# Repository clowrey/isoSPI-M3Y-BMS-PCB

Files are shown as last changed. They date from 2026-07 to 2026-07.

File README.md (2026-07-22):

# CellKeeper BMS — Rev1

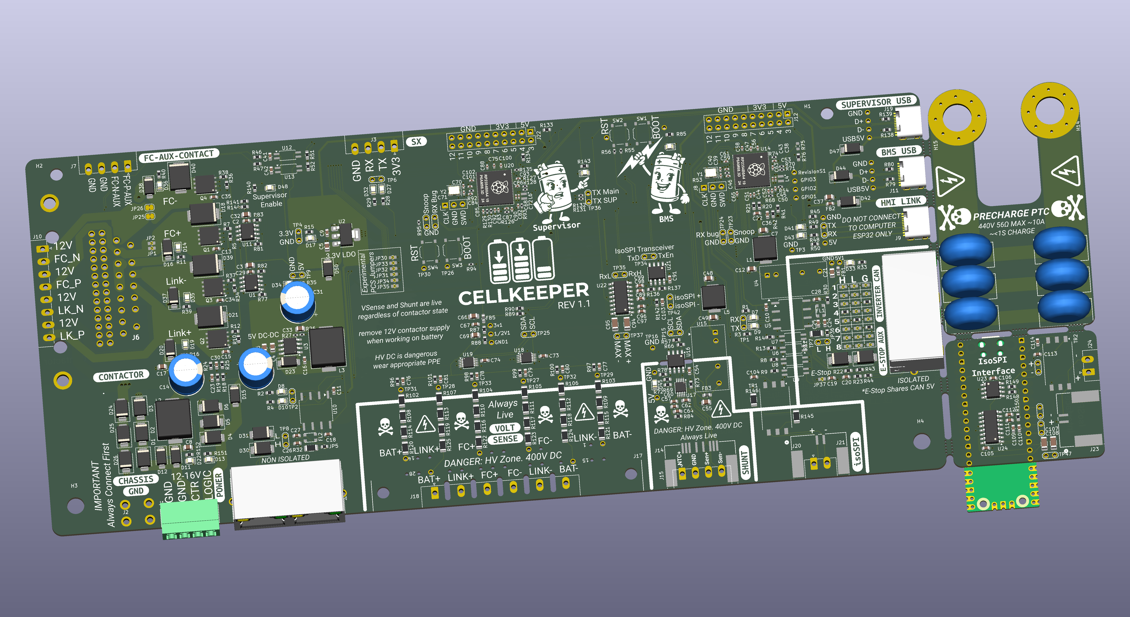
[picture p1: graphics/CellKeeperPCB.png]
CellKeeper PCB


KiCad PCB design for the **CellKeeper Battery Management System**, a replacement BMS controller for battery packs using the isoSPI protocol.

## Overview

- **MCU:** Raspberry Pi RP2354B (dual Cortex-M33 @ 150 MHz)
- **Current sensing:** TI INA228 (20-bit ADC, shunt-based)
- **Pack voltage:** 6-channel monitoring via precision dividers
- **BMB communication:** isoSPI master with galvanic isolation (Manchester encoding via PIO)
- **CAN bus:** 500 kbps, hardware transceiver
- **Contactor control:** 4-channel PWM outputs with inrush limiting
- **Input:** 12 V nominal; rated for up to 400 V DC pack voltage

## Repository Contents

| Path | Description |
|---|---|
| `CellKeeper.kicad_pro` | KiCad project file |
| `CellKeeper.kicad_sch` | Schematic |
| `CellKeeper.kicad_pcb` | PCB layout |
| `CellKeeper_Local.kicad_sym` / `CellKeeper_Local.pretty/` | Local symbol and footprint libraries |
| `CellKeeper.3dshapes/` | 3D models |
| `graphics/` | Silkscreen artwork and images |
| `production/` | Manufacturing outputs |
| `python_scripts/` | Utility scripts |

## Getting Started

1. Install [KiCad 10.0+](https://www.kicad.org/download/)
2. Clone this repository
3. Open `CellKeeper.kicad_pro` — project libraries load from the local `sym-lib-table` and `fp-lib-table`

## Safety

⚠️ This board interfaces with 400 V battery packs that can deliver **lethal** current. Only qualified personnel should work on high-voltage systems. This is a Rev1 development design — untested, no warranty, use at your own risk.

## Acknowledgments

- **Damien Maguire & Tom de Bree** — Original BATMan BMS software

## License

GPL-3.0 — see [LICENSE](LICENSE).

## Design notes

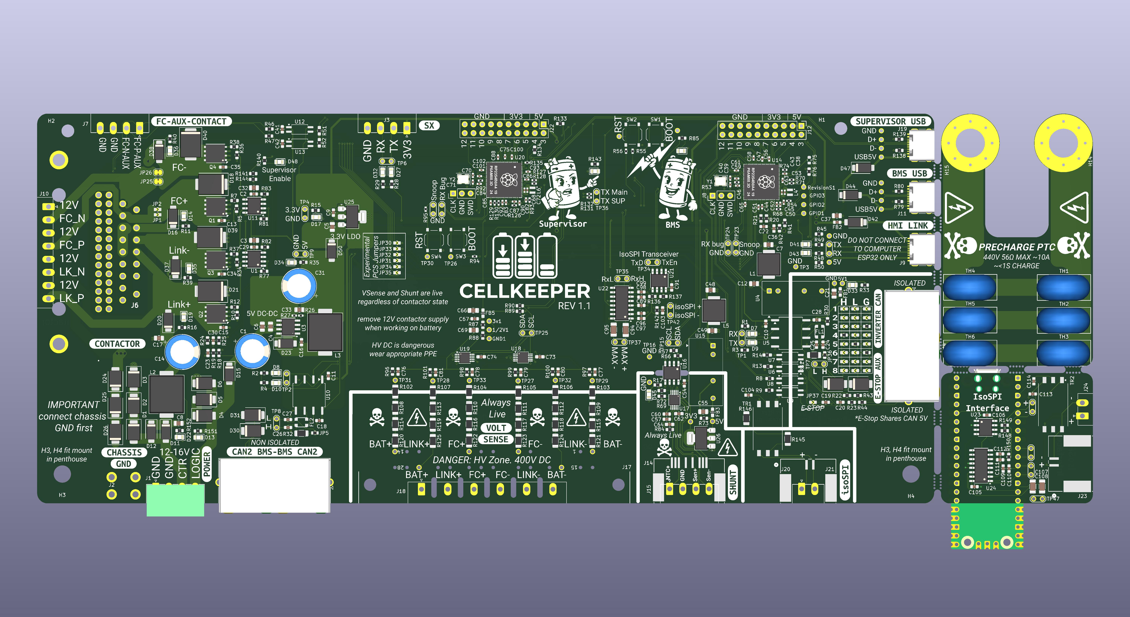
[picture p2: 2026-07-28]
CellKeeper_1v1.jpg

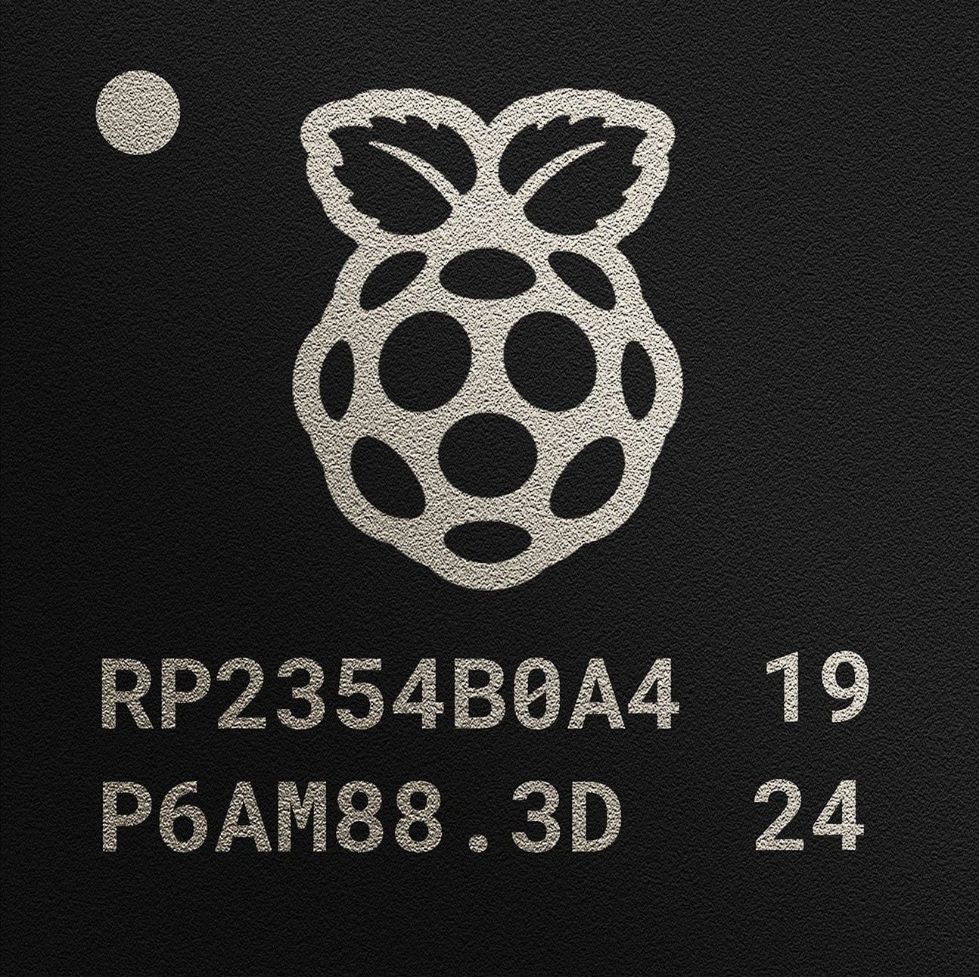
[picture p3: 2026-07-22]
graphics/raspberry-pi-rp2354b.jpg

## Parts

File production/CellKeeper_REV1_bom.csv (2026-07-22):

Designator | Footprint | Quantity | Value | LCSC Part #
1/2V1, 3V1, 5V1, GND1, GPIO1, GPIO2, GPIO3 | BMS_Library__TestPoint_THTPad_D1.5mm_Drill1.0mm | 7 | TP
A1 | Module__RaspberryPi_Pico_Common_Unspecified | 1 | RaspberryPi_Pico
C1, C14, C31 | Capacitor_THT__CP_Radial_D10.0mm_P5.00mm | 3 | 680uF | C46550429
C10, C104, C105, C106, C11, C114, C13, C15, C16, C18, C2, C22, C23, C28, C29, C30, C34, C35, C36, C54, C60, C76, C77, C78, C79, C80, C81, C89, C91 | Capacitor_SMD__C_0603_1608Metric | 29 | 100nF | C14663
C100, C101, C102, C44, C46, C47, C50, C51, C53, C56, C58, C59, C61, C63, C65, C75, C83, C84, C85, C86, C88, C90, C92, C93 | Capacitor_SMD__C_0402_1005Metric | 24 | 100n | C1525
C103, C113, C24, C25, C26, C27 | Capacitor_SMD__C_0603_1608Metric | 6 | 100pF | C14858
C107, C108, C94, C95 | Capacitor_SMD__C_1206_3216Metric | 4 | 1nF | C9196
C109, C110, C111, C112, C19, C20, C41, C42, C57, C67, C96, C97, C98, C99 | Capacitor_SMD__C_0603_1608Metric | 14 | 1uF | C15849
C12, C33, C37, C48, C49, C5, C69, C7 | Capacitor_SMD__C_0805_2012Metric | 8 | 22uF | C45783
C17, C21, C3, C32, C4, C55, C6, C8 | Capacitor_SMD__C_0805_2012Metric | 8 | 10uF | C440198
C38, C43, C68, C72 | RP2350_80QFN_minimal__C_0402_1005Metric_small_pads | 4 | 4.7u | C23733
C39, C40, C70, C71 | Capacitor_SMD__C_0402_1005Metric | 4 | 15pF | C1548
C45, C52, C82, C87 | Capacitor_SMD__C_0402_1005Metric | 4 | 4.7u | C23733
C62, C64, C73, C74 | Capacitor_SMD__C_0603_1608Metric_Pad1.08x0.95mm_HandSolder | 4 | 100nf | C14663
C66 | Capacitor_SMD__C_0805_2012Metric_Pad1.18x1.45mm_HandSolder | 1 | 10uF | C440198
C9 | Capacitor_SMD__C_0603_1608Metric | 1 | 4.7uF | C19666
D1, D2, D24, D25, D26, D28, D29, D3, D30, D31, D4, D5, D6 | Diode_SMD__D_SMB | 13 | SMB6.8CA | C78395
D10, D27, D41, D46, D49, D9 | LED_SMD__LED_0805_2012Metric | 6 | Red | C84256
D11, D12, D15, D16, D20, D23, D37, D38, D42, D44, D47, D50 | Diode_SMD__D_SMA | 12 | SS54 | C22452
D13, D17, D22, D33, D34, D45 | LED_SMD__LED_0805_2012Metric | 6 | White | C34499
D14, D19, D32, D35, D36, D43, D48, D7, D8 | LED_SMD__LED_0805_2012Metric | 9 | Green | C2297
D18, D21, D39, D40 | Diode_SMD__D_SMC | 4 | SMCJ33CA | C224050
FB1, FB3, FB5 | Inductor_SMD__L_0603_1608Metric_Pad1.05x0.95mm_HandSolder | 3 | 600R@100MHz | C1002
FB2 | Capacitor_SMD__C_0603_1608Metric | 1 | 120Ω@100MHz | C14709
FL1, FL2 | BMS_Library__FILTER-SMD_4P-L3.2-W2.5-BL | 2 | SDCW3225S-2-102TF | C192586
J1 | BMS_Library__PhoenixContact_MC_1_5_4-G-3.81_1x04_P3.81mm_Horizontal_1.4mmPin | 1 | Screw_Terminal_01x04
J11, J19, J9 | BMS_Library__USB_C_Receptacle_HRO_TYPE-C-31-M-12 | 3 | USB_C_Receptacle_USB2.0_16P | C2765186
J14 | BMS_Library__CONN_ZE05H-8DP-2H_HIR | 1 | OEM Shunt Connector | C17284895
J17 | BMS_Library__CONN_173864-1_TYC_Empty_Pins | 1 | OEM HV Sense Connector | C573648
J2 | BMS_Library__XFCN_T34008_M3_Terminal_Frame_PCB | 1 | Screw_Terminal_01x01 | C481446
J20, J23 | BMS_Library__CONN_SD-34912-001_02_MOL | 2 | OEM Connector | C587318
J4, J5 | Connector_RJ__RJ45_HCTL_HC-RJ45-5JA-2-2-Y | 2 | 8P8C_LED_Shielded_x2 | C3010546
J6 | BMS_Library__S44BRAD1AK | 1 | OEM Connector
JP10, JP11, JP15, JP36, JP5, JP6 | BMS_Library__J_0603_jumper | 6 | 0r | C21189
L1, L5 | Inductor_SMD__L_Changjiang_FXL0630 | 2 | 6.8uh | C167221
L2, L3 | Inductor_SMD__L_Changjiang_FXL1040 | 2 | 22uh 5.5A | C475917
L4, L6 | RP2350_80QFN_minimal__L_pol_2016 | 2 | 3.3uh | C42411119
Q1, Q2, Q3, Q4 | BMS_Library__TDSON-8_5x6_ | 4 | BSC0805LS | C534374
R1, R100, R101, R11, R140, R16, R17, R2, R29, R33, R35, R39, R40, R41, R6, R78, R96, R97, R98, R99 | Resistor_SMD__R_0603_1608Metric | 20 | 24k | C23352
R10, R18, R24, R34, R36, R5 | Resistor_SMD__R_0603_1608Metric | 6 | 100k | C25803
R102, R103, R104, R105, R106, R107, R108, R109, R110, R111, R112, R113, R114, R115, R116, R117, R118, R119, R120, R121, R122, R123, R124, R125 | Resistor_SMD__R_1206_3216Metric | 24 | 3M | C488822
R12, R37, R38, R7 | Resistor_SMD__R_0603_1608Metric | 4 | 33R | C23140
R126, R54, R68, R93 | Resistor_SMD__R_0402_1005Metric | 4 | 33r | C25105
R127, R128, R70, R71 | Resistor_SMD__R_0402_1005Metric | 4 | 22R | C25092
R129, R130, R131, R132, R135, R27, R53, R55, R56, R74, R92, R94, R95 | Resistor_SMD__R_0402_1005Metric | 13 | 1k | C11702
R13, R14, R51, R52 | Resistor_SMD__R_0603_1608Metric_Pad0.98x0.95mm_HandSolder | 4 | 10k | C25804
R133, R134, R141, R22, R23, R46, R47, R48, R49, R8, R9 | Resistor_SMD__R_0603_1608Metric | 11 | 1k | C21190
R136, R137, R148, R149 | Resistor_SMD__R_0603_1608Metric | 4 | 47r | C23182
R138, R139, R143, R144, R45, R57, R66, R69, R72, R77, R79, R80, R81, R82, R83, R85, R89, R90 | Resistor_SMD__R_0603_1608Metric | 18 | 5.1k | C23186
R142, R150 | Resistor_SMD__R_0603_1608Metric | 2 | 100R | C22775
R145, R146 | Resistor_SMD__R_1206_3216Metric | 2 | 1M | C17927
R15, R19, R20, R21, R25, R28, R3, R4, R42, R50, R84 | Resistor_SMD__R_0603_1608Metric | 11 | 10k | C25804
R26 | Resistor_SMD__R_0402_1005Metric | 1 | 3.3k | C25890
R30, R73 | Resistor_SMD__R_0603_1608Metric | 2 | 510r | C23193
R31, R32 | Resistor_SMD__R_1206_3216Metric | 2 | 120r | C17909
R43, R44 | Resistor_SMD__R_0603_1608Metric | 2 | 2.2k | C4190
R76 | Resistor_SMD__R_0603_1608Metric | 1 | 0r | C21189
R87, R88 | Resistor_SMD__R_0603_1608Metric | 2 | 220r | C22962
SW1, SW2, SW3, SW4 | Button_Switch_SMD__SW_Push_1P1T_XKB_TS-1187A | 4 | TS-1187A-B-A-B | C318884
TH1, TH2, TH3, TH4, TH5, TH6 | BMS_Library__RV_Disc_D15.5mm_W7.5mm_P5.0mm | 6 | B59451C1130B070 | C2762811
TR1, TR2 | BMS_Library__HM2113ZNLT | 2 | HM2113ZNLT | C5730533
U1, U11 | Package_SO__SOIC-8_3.9x4.9mm_P1.27mm | 2 | UCC27524DR | C465729
U10, U5 | Package_SO__SOP-8_6.62x9.15mm_P2.54mm | 2 | ISO1050DUB | C16428
U12, U13, U6, U7, U8, U9 | Package_SO__SSOP-4_4.4x2.6mm_P1.27mm | 6 | LTV-217-B-G | C115450
U14, U20 | RP2350_80QFN_minimal__RP2350-QFN-80-1EP_10x10_P0.4mm_EP3.4x3.4mm_ThermalVias | 2 | RP2354B | C39843328
U15, U4 | BMS_Library__H0505S-1WR2 | 2 | F0505S-1WR3 | C7465182
U16 | Package_SO__SOIC-8_3.9x4.9mm_P1.27mm | 1 | ISO1540 | C179739
U17 | Package_SO__TSSOP-10_3x3mm_P0.5mm | 1 | INA228 | C5214669
U18, U19 | Package_SO__TSSOP-10_3x3mm_P0.5mm | 2 | ADS1115 | C37593
U2 | Package_TO_SOT_SMD__SOT-223-3_TabPin2 | 1 | AMS1117-3.3 | C6186
U21, U23 | Package_SO__SOIC-8_3.9x4.9mm_P1.27mm | 2 | SP3485EN-L/TR | C8963
U22, U24 | Package_SO__SOIC-16_3.9x9.9mm_P1.27mm | 2 | AM26LV32EIDR | C527448
U3 | Package_SO__TI_SO-PowerPAD-8_ThermalVias | 1 | TPS5430DDAR | C9864
Y1, Y2 | Crystal__Crystal_SMD_3225-4Pin_3.2x2.5mm | 2 | ABM8-272-T3 | C20625731

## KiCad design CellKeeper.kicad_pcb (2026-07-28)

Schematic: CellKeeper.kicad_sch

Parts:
1/2V1, 3v1, 5V1: TP; BMS_Library__TestPoint_THTPad_D1.5mm_Drill1.0mm
A1: RaspberryPi_Pico; Module__RaspberryPi_Pico_Common_Unspecified
BT1, BT2, BT3, BT4, BT5, BT6, BT7, BT8: ~100V Brick
C1, C14, C31: 680uF; Capacitor_THT__CP_Radial_D10.0mm_P5.00mm; Voltage 35V Polymer; JLCPCB Part # C46550429
C2, C10, C11, C13, C15, C16, C18, C22, C23, C28, C29, C30, C34, C35, C36, C54, C60, C89, C91, C104, C105, C106, C114: 100nF; Capacitor_SMD__C_0603_1608Metric; JLCPCB Part # C14663
C3, C4, C6, C8, C17, C32: 10uF; Capacitor_SMD__C_0805_2012Metric; Voltage 50V; JLCPCB Part # C440198
C5, C7, C12, C33, C37, C48, C49, C69: 22uF; Capacitor_SMD__C_0805_2012Metric; Voltage 25V X5R; JLCPCB Part # C45783
C9: 4.7uF; Capacitor_SMD__C_0603_1608Metric; JLCPCB Part # C19666
C19, C20, C41, C42, C67, C96, C97, C98, C99, C109, C110, C111, C112: 1uF; Capacitor_SMD__C_0603_1608Metric; JLCPCB Part # C15849
C21, C55, C116: 10uF; Capacitor_SMD__C_0805_2012Metric; Voltage 50V X5R; JLCPCB Part # C440198
C24, C25, C26, C27, C103, C113: 100pF; Capacitor_SMD__C_0603_1608Metric; JLCPCB Part # C14858
C38, C43, C68, C72: 4.7u; RP2350_80QFN_minimal__C_0402_1005Metric_small_pads; JLCPCB Part # C23733
C39, C40, C70, C71: 15pF; Capacitor_SMD__C_0402_1005Metric; JLCPCB Part # C1548
C44, C46, C47, C50, C51, C53, C56, C58, C59, C61, C63, C65, C75, C83, C84, C85, C86, C88, C90, C92, C93, C100, C101, C102: 100n; Capacitor_SMD__C_0402_1005Metric; JLCPCB Part # C1525
C45, C52, C82, C87: 4.7u; Capacitor_SMD__C_0402_1005Metric; JLCPCB Part # C23733
C62, C64: 100nf; Capacitor_SMD__C_0603_1608Metric_Pad1.08x0.95mm_HandSolder; JLCPCB Part # C14663
C66: 10uF; Capacitor_SMD__C_0805_2012Metric_Pad1.18x1.45mm_HandSolder; Voltage 50V; JLCPCB Part # C440198
C73, C74: 100nF; Capacitor_SMD__C_0603_1608Metric_Pad1.08x0.95mm_HandSolder; JLCPCB Part # C14663
C76, C77, C78, C79, C80, C81: 100nf; Capacitor_SMD__C_0603_1608Metric; JLCPCB Part # C14663
C94, C95, C107, C108: 1nF; Capacitor_SMD__C_1206_3216Metric; JLCPCB Part # C9196
Cell1, Cell2, Cell3: Battery_Cell
D1, D2, D3, D4, D5, D6, D24, D25, D26, D28, D29, D30, D31: SMB6.8CA; Diode_SMD__D_SMB; JLCPCB Part # C78395
D7, D8, D14, D19, D32, D35, D36, D43, D48: Green; LED_SMD__LED_0805_2012Metric; JLCPCB Part # C2297
D9, D10, D27, D41, D46, D49: Red; LED_SMD__LED_0805_2012Metric; JLCPCB Part # C84256
D11, D12, D15, D16, D20, D23, D37, D38, D42, D44, D47, D50: SS54; Diode_SMD__D_SMA; JLCPCB Part # C22452
D13, D17, D22, D33, D34, D45: White; LED_SMD__LED_0805_2012Metric; JLCPCB Part # C34499
D18, D21, D39, D40: SMCJ33CA; Diode_SMD__D_SMC; JLCPCB Part # C224050
F1, F3: Pyro Fuse
F2, F4: 63A HV DC
FB1, FB3, FB5: 600R@100MHz; Inductor_SMD__L_0603_1608Metric_Pad1.05x0.95mm_HandSolder; JLCPCB Part # C1002
FB2: 120Ω@100MHz; Capacitor_SMD__C_0603_1608Metric; JLCPCB Part # C14709
FL1, FL2: SDCW3225S-2-102TF; BMS_Library__FILTER-SMD_4P-L3.2-W2.5-BL; JLCPCB Part # C192586
GND1: TP; BMS_Library__TestPoint_THTPad_D1.5mm_Drill1.0mm
GPIO1, GPIO2, GPIO3: TP; BMS_Library__TestPoint_THTPad_D1.5mm_Drill1.0mm
H1, H2: MountingHole_Pad; MountingHole__MountingHole_3.7mm; not fitted
H3, H4: MountingHole_Pad; MountingHole__MountingHole_5mm; not fitted
H5, H6, H7, H8, H9, H10, H11, H12, H13: Mouse Bites 2mm; BMS_Library__mouse-bite-2mm-slot-min
H14, H15: MountingHole_Pad; MountingHole__MountingHole_8.4mm_M8_Pad_Via
J1: Screw_Terminal_01x04; BMS_Library__PhoenixContact_MC_1_5_4-G-3.81_1x04_P3.81mm_Ho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
J2: Screw_Terminal_01x01; BMS_Library__XFCN_T34008_M3_Terminal_Frame_PCB; JLCPCB Part # C481446
J3, J7, J15: Screw_Terminal_01x04; BMS_Library__PhoenixContact_MC_1_5_4-G-3.81_1x04_P3.81mm_Ho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; not fitted
J4, J5: 8P8C_LED_Shielded_x2; Connector_RJ__RJ45_HCTL_HC-RJ45-5JA-2-2-Y; JLCPCB Part # C3010546
J6: OEM Connector; BMS_Library__S44BRAD1AK; Mfr. # S44B-RAD1AK
J8, J16: Conn_01x03; Connector_PinHeader_2.54mm__PinHeader_1x03_P2.54mm_Vertical; not fitted
J9, J11, J19: USB_C_Receptacle_USB2.0_16P; BMS_Library__USB_C_Receptacle_HRO_TYPE-C-31-M-12; JLCPCB Part # C2765186
J10: 3.81P Screw Terminal; BMS_Library__PhoenixContact_MC_1_5_8-G-3.81_1x08_P3.81mm_Ho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; not fitted
J12, J22: Conn_02x10_Odd_Even; Connector_PinHeader_2.54mm__PinHeader_2x10_P2.54mm_Vertical; not fitted
J13: USB_C_Receptacle_USB2.0_16P
J14: OEM Shunt Connector; BMS_Library__CONN_ZE05H-8DP-2H_HIR; MFR.Part # ZE05H-8DP-2H; JLCPCB Part # C17284895
J17: OEM HV Sense Connector; BMS_Library__CONN_173864-1_TYC_Empty_Pins; MFR Part # 173864-1; JLCPCB Part # C573648
J18: 7.62mm Pitch Screw Terminal; Connector_Phoenix_GMSTB__PhoenixContact_GMSTBA_2_5_6-G-7_62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; not fitted
J20, J23: OEM Connector; BMS_Library__CONN_SD-34912-001_02_MOL; MFR.Part # 349128020; JLCPCB Part # C587318
J21, J24: 3.81P Screw Terminal; BMS_Library__PhoenixContact_MC_1_5_2-G-3.81_1x02_P3.81mm_Ho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; not fitted
JP1, JP2, JP3, JP4, JP7, JP8, JP9, JP12, JP13, JP14, JP16, JP17, JP18, JP19, JP20, JP21, JP22, JP23, JP24, JP27, JP28, JP29, JP30, JP31, JP32, JP33, JP34, JP35, JP37: 0r; BMS_Library__J_0603_jumper; JLCPCB Part # C21189; not fitted
JP5, JP6, JP10, JP11, JP15, JP36: 0r; BMS_Library__J_0603_jumper; JLCPCB Part # C21189
JP25, JP26: jumper-bridged; Jumper__SolderJumper-2_P1.3mm_Bridged_RoundedPad1.0x1.5mm
K1, K6: Link Positive
K2, K7: Link Negative
K3, K9: FC Positive
K4, K8: FC Negative
K5, K10: Inverter
L1, L5: 6.8uh; Inductor_SMD__L_Changjiang_FXL0630; JLCPCB Part # C167221
L2, L3: 22uh 5.5A; Inductor_SMD__L_Changjiang_FXL1040; JLCPCB Part # C475917
L4, L6: 3.3uh; RP2350_80QFN_minimal__L_pol_2016; JLCPCB Part # C42411119
Q1, Q2, Q3, Q4: BSC0805LS; BMS_Library__TDSON-8_5x6_; JLCPCB Part # C534374
R1, R2, R11, R16, R29, R33, R35, R39, R40, R41, R96, R97, R98, R99, R100, R101, R140: 24k; Resistor_SMD__R_0603_1608Metric; JLCPCB Part # C23352
R3, R4, R15, R17, R19, R20, R21, R25, R28, R42, R50, R84: 10k; Resistor_SMD__R_0603_1608Metric; JLCPCB Part # C25804
R5, R10, R18, R24, R34, R36, R151, R152: 100k; Resistor_SMD__R_0603_1608Metric; JLCPCB Part # C25803
R7, R12, R37, R38: 33R; Resistor_SMD__R_0603_1608Metric; JLCPCB Part # C23140
R8, R9, R22, R23, R46, R47, R48, R49, R133, R134, R141: 1k; Resistor_SMD__R_0603_1608Metric; JLCPCB Part # C21190
R13, R14, R51, R52: 10k; Resistor_SMD__R_0603_1608Metric_Pad0.98x0.95mm_HandSolder; JLCPCB Part # C25804
R26: 3.3k; Resistor_SMD__R_0402_1005Metric; JLCPCB Part # C25890
R27, R53, R55, R56, R74, R92, R94, R95, R129, R130, R131, R132, R135: 1k; Resistor_SMD__R_0402_1005Metric; JLCPCB Part # C11702
R30, R73: 510r; Resistor_SMD__R_0603_1608Metric; JLCPCB Part # C23193
R31, R32: 120r; Resistor_SMD__R_1206_3216Metric; JLCPCB Part # C17909
R43, R44: 2.2k; Resistor_SMD__R_0603_1608Metric; JLCPCB Part # C4190
R45, R57, R66, R69, R72, R77, R79, R80, R81, R82, R83, R85, R89, R90, R138, R139, R143, R144: 5.1k; Resistor_SMD__R_0603_1608Metric; JLCPCB Part # C23186
R54, R68, R93, R126: 33r; Resistor_SMD__R_0402_1005Metric; JLCPCB Part # C25105
R58, R59, R60, R61, R62, R63, R64, R65: 18r
R67: 12.24R
R70, R71, R127, R128: 22R; Resistor_SMD__R_0402_1005Metric; JLCPCB Part # C25092
R75: 47k; Resistor_SMD__R_0603_1608Metric; JLCPCB Part # C25819; not fitted
R76: 0r; Resistor_SMD__R_0603_1608Metric; JLCPCB Part # C21189
R86, R147: 25296nΩ
R87, R88: 220r; Resistor_SMD__R_0603_1608Metric; JLCPCB Part # C22962
R91: 27R 50W
R102, R103, R104, R105, R106, R107, R108, R109, R110, R111, R112, R113, R114, R115, R116, R117, R118, R119, R120, R121, R122, R123, R124, R125: 3M; Resistor_SMD__R_1206_3216Metric; JLCPCB Part # C488822
R136, R137, R148, R149: 47r; Resistor_SMD__R_0603_1608Metric; JLCPCB Part # C23182
R142, R150: 100R; Resistor_SMD__R_0603_1608Metric; JLCPCB Part # C22775
R145, R146: 1M; Resistor_SMD__R_1206_3216Metric; JLCPCB Part # C17927
RevisionS1: TP; BMS_Library__TestPoint_THTPad_D1.5mm_Drill1.0mm
SW1, SW2, SW3, SW4: TS-1187A-B-A-B; Button_Switch_SMD__SW_Push_1P1T_XKB_TS-1187A; JLCPCB Part # C318884
TH1, TH2, TH3, TH4, TH5, TH6: B59451C1130B070; BMS_Library__RV_Disc_D15.5mm_W7.5mm_P5.0mm; JLCPCB Part # C2762811
TP1, TP2, TP4, TP6, TP7, TP8, TP9, TP10, TP15, TP23, TP24, TP25, TP34, TP35, TP36, TP37, TP43, TP44, TP45, TP46, TP47, TP48: TestPoint_2Pole; BMS_Library__TestPoint_2Pads_Pitch2.54mm_Pad1.5_Drill1.0mm
TP3, TP5, TP11, TP12, TP13, TP14, TP16, TP17, TP18, TP19, TP20, TP21, TP22, TP26, TP27, TP28, TP29, TP30, TP31, TP32, TP33, TP38, TP39, TP40, TP41, TP49: TP; BMS_Library__TestPoint_THTPad_D1.5mm_Drill1.0mm
TP42: TestPoint_2Pole; BMS_Library__TestPoint_2Pads_Pitch2.54mm_Pad1.5_Drill1.0mm; not fitted
TR1, TR2: HM2113ZNLT; BMS_Library__HM2113ZNLT; JLCPCB Part # C5730533
U1, U11: UCC27524DR; Package_SO__SOIC-8_3.9x4.9mm_P1.27mm; JLCPCB Part # C465729
U3: TPS5430DDAR; Package_SO__TI_SO-PowerPAD-8_ThermalVias; LCSC Part C9864
U4, U15: F0505S-1WR3; BMS_Library__H0505S-1WR2; JLCPCB Part # C7465182
U5, U10: ISO1050DUB; Package_SO__SOP-8_6.62x9.15mm_P2.54mm; LCSC Part # C16428
U6, U7, U8, U9, U12, U13: LTV-217-B-G; Package_SO__SSOP-4_4.4x2.6mm_P1.27mm; JLCPCB Part # C115450
U14, U20: RP2354B; RP2350_80QFN_minimal__RP2350-QFN-80-1EP_10x10_P0.4mm_EP3.4x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; JLCPCB Part # C39843328
U16: ISO1540; Package_SO__SOIC-8_3.9x4.9mm_P1.27mm; JLCPCB Part # C179739
U17: INA228; Package_SO__TSSOP-10_3x3mm_P0.5mm; JLCPCB Part # C5214669
U18, U19: ADS1115; Package_SO__TSSOP-10_3x3mm_P0.5mm; LCSC Part # C37593
U21, U23: SP3485EN-L/TR; Package_SO__SOIC-8_3.9x4.9mm_P1.27mm; JLCPCB Part # C8963
U22, U24: AM26LV32EIDR; Package_SO__SOIC-16_3.9x9.9mm_P1.27mm; JLCPCB Part # C527448
U25, U26: TLV1117LV33DCYR; Package_TO_SOT_SMD__SOT-223-3_TabPin2; JLCPCB Part # C15578
Y1, Y2: ABM8-272-T3; Crystal__Crystal_SMD_3225-4Pin_3.2x2.5mm; JLCPCB Part # C20625731

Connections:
3.3V Sense: C22.2, R20.2, R21.1, U14.49 (GPIO40_ADC0)
5V Sense: C36.2, R41.2, R42.1, U14.52 (GPIO41_ADC1)
+1V1: C43.1, C44.1, C46.1, C47.1, L4.1, U14.10 (DVDD), U14.32 (DVDD), U14.51 (DVDD), U14.65 (VREG_FB)
+1V1_2: C72.1, C75.1, C83.1, C84.1, L6.1, U20.10 (DVDD), U20.32 (DVDD), U20.51 (DVDD), U20.65 (VREG_FB)
+3.3V: C9.2, C10.1, C11.1, C38.1, C50.1, C51.1, C53.1, C56.1, C58.1, C59.1, C61.1, C63.1, C65.1, C66.2, C68.1, C85.1, C86.1, C88.1, C89.1, C90.1, C91.2, C92.1, C93.1, C100.1, C101.1, C102.1, D7.2 (A), D9.2 (A), D41.2 (A), D43.2 (A), FB5.1, J3.1, J12.5, J12.7, J12.9, J22.5, J22.7, J22.9, JP35.2, R2.1, R4.1, R15.1, R20.1, R28.1, R29.1, R54.2, R57.1, R66.1, R68.2, R75.1, R89.1, R90.1, R93.2, R126.2, R135.1, TP4.2, U5.1 (VCC1), U6.4, U7.4, U10.1 (VCC1), U12.4, U13.4, U14.5 (IOVDD), U14.15 (IOVDD), U14.24 (IOVDD), U14.29 (IOVDD), U14.41 (IOVDD), U14.50 (IOVDD), U14.60 (IOVDD), U14.64 (VREG_VIN), U14.68 (USB_OTP_VDD), U14.69 (QSPI_IOVDD), U14.76 (IOVDD), U16.1 (VCC1), U20.5 (IOVDD), U20.15 (IOVDD), U20.24 (IOVDD), U20.29 (IOVDD), U20.41 (IOVDD), U20.50 (IOVDD), U20.60 (IOVDD), U20.64 (VREG_VIN), U20.68 (USB_OTP_VDD), U20.69 (QSPI_IOVDD), U20.76 (IOVDD), U21.8 (VCC), U22.4 (G), U22.16 (VDD), U25.2 (VO)
+3.3V2: A1.36 (3V3), C105.1, C106.2, U23.8 (VCC), U24.4 (G), U24.16 (VDD)
+3.3VSen: 3v1.1 (1_1), C67.2, C73.2, C74.2, FB5.2, R87.1, U18.8 (VDD), U19.1 (ADDR), U19.8 (VDD)
+5V: C2.2, C3.2, C7.2, C18.2, C29.2, C31.1, C32.2, C33.2, C37.2, C41.2, C42.2, C48.2, D50.2 (A), FB2.2, J12.1, J12.3, J22.1, J22.3, L1.2, L3.1, L5.2, R26.1, R35.1, R41.1, TP9.2, U1.6 (V_{DD}), U10.8 (VCC2), U11.6 (V_{DD}), U12.1, U13.1
+LDO_IN: C5.2, D44.1 (K), D47.1 (K), D50.1 (K), U25.3 (VI)
/Blue: J4.4, JP15.2, JP16.1, JP18.1
/Brown: J4.8, JP19.2, JP20.1, JP23.1
/CAN2 H: C26.2, D30.2 (A2), FL2.2, J5.4, J5.16, R32.2, TP8.2
/CAN2 L: C27.1, D31.1 (A1), FL2.3, J5.5, J5.17, JP5.1, TP8.1
/CAN 5V: 5V1.1 (1_1), C28.2, FB1.2, R22.2, R30.1, R33.1, R43.2, U5.8 (VCC2)
/CAN H: C24.2, D28.2 (A2), FL1.2, JP3.1, JP7.1, JP9.1, JP13.1, JP15.1, JP19.1, JP21.1, JP27.1, JP36.1, TP7.2
/CAN L: C25.1, D29.1 (A1), FL1.3, JP4.2, JP8.2, JP10.2, JP14.2, JP16.2, JP20.2, JP22.2, JP28.2, R31.1, TP7.1
/Contactor_Input: D1.2 (A2), D11.2 (A), D12.2 (A), J1.3
/FC Neg: H15.1 (1_1), K4.13, K8.13, K10.2, TH4.2, TH5.2, TH6.2
/FC-CTR-NEG-AUX-D: J6.17, J7.2, R47.1
/FC-CTR-POS-AUX-D: J6.18, J7.1, R46.1
/FC-Neg-Jumper: C35.2, D36.1 (K), D38.2 (A), D40.2 (A2), JP25.1 (A), JP26.1 (A), Q4.5 (D)
/FC-Pos-Jumper: C13.2, D14.1 (K), D16.2 (A), D18.2 (A2), JP1.1, JP2.1, Q1.5 (D)
/GPIO0: R74.2, U14.77 (GPIO0)
/GPIO3: J12.2, U14.80 (GPIO3)
/GPIO25: R85.1, U14.26 (GPIO25)
/GPIO44_ADC4: GPIO1.1 (1_1), U14.55 (GPIO44_ADC4)
/GPIO45_ADC5: GPIO2.1 (1_1), U14.56 (GPIO45_ADC5)
/GPIO46_ADC6: GPIO3.1 (1_1), U14.57 (GPIO46_ADC6)
/GPIO47_ADC7: R75.2, R76.1, RevisionS1.1 (1_1), U14.58 (GPIO47_ADC7)
/Grn: J4.6, JP7.2, JP8.1, JP11.1
/Logic_Input: D4.2 (A2), D15.2 (A), J1.4, R151.2
/MCU2_GPIO0: R135.2, U20.77 (GPIO0)
/MCU2_GPIO1: R131.2, U20.78 (GPIO1)
/MCU2_GPIO2: R132.2, U20.79 (GPIO2)
/MCU2_GPIO3: J22.2, U20.80 (GPIO3)
/MCU2_GPIO4: J22.4, U20.1 (GPIO4)
/MCU2_GPIO5: J22.6, U20.2 (GPIO5)
/MCU2_GPIO6: J22.8, R133.1, U20.3 (GPIO6)
/MCU2_GPIO7: J22.10, U20.4 (GPIO7)
/MCU2_GPIO8: J22.12, R134.1, U20.6 (GPIO8)
/MCU2_GPIO9: J22.14, U20.7 (GPIO9)
/MCU2_GPIO10: J22.16, U20.8 (GPIO10)
/MCU2_GPIO12: J22.20, U20.11 (GPIO12)
/MCU2_GPIO13: U20.12 (GPIO13)
/MCU2_GPIO14: R140.1, R141.1, U20.13 (GPIO14)
/MCU2_GPIO15: U20.14 (GPIO15)
/MCU2_GPIO16: U20.16 (GPIO16)
/MCU2_GPIO17: U20.17 (GPIO17)
/MCU2_GPIO18: U20.18 (GPIO18)
/MCU2_GPIO19: U20.19 (GPIO19)
/MCU2_GPIO20: U20.20 (GPIO20)
/MCU2_GPIO21: U20.21 (GPIO21)
/MCU2_GPIO22: U20.22 (GPIO22)
/MCU2_GPIO23: U20.23 (GPIO23)
/MCU2_GPIO24: U20.25 (GPIO24)
/MCU2_GPIO25: R143.1, U20.26 (GPIO25)
/MCU2_GPIO26: U20.27 (GPIO26)
/MCU2_GPIO27: U20.28 (GPIO27)
/MCU2_GPIO33: U20.42 (GPIO33)
/MCU2_GPIO34: U20.43 (GPIO34)
/MCU2_GPIO35: U20.44 (GPIO35)
/MCU2_GPIO36: U20.45 (GPIO36)
/MCU2_GPIO37: U20.46 (GPIO37)
/MCU2_GPIO38: R129.2, U20.47 (GPIO38)
/MCU2_GPIO39: R130.2, U20.48 (GPIO39)
/Orange: J4.2, JP21.2, JP22.1, JP24.1
/PH: C16.1, D23.1 (K), L3.2, U3.8 (PH)
/QSPI2_SCLK: U20.71 (QSPI_SCLK)
/QSPI2_SD0: U20.72 (QSPI_SD0)
/QSPI2_SD1: U20.74 (QSPI_SD1)
/QSPI2_SD2: U20.73 (QSPI_SD2)
/QSPI2_SD3: U20.70 (QSPI_SD3)
/QSPI2_SS: R94.1, U20.75 (QSPI_SS)
/QSPI_SCLK: U14.71 (QSPI_SCLK)
/QSPI_SD0: U14.72 (QSPI_SD0)
/QSPI_SD1: U14.74 (QSPI_SD1)
/QSPI_SD2: U14.73 (QSPI_SD2)
/QSPI_SD3: U14.70 (QSPI_SD3)
/QSPI_SS: R55.1, U14.75 (QSPI_SS)
/RUN: R56.2, SW2.2, TP14.1 (1_1)
/RUN_2: R95.1, U20.35 (RUN)
/SWCLK: J8.1, U14.33 (SWCLK)
/SWCLK_2: J16.1, U20.33 (SWCLK)
/SWD: J8.3, U14.34 (SWD)
/SWD_2: J16.3, U20.34 (SWD)
/Serial API 5V Diode: D42.1 (K), J9.A4 (VBUS), J9.A9 (VBUS), J9.B4 (VBUS), J9.B9 (VBUS), TP13.1 (1_1)
/Serial API RX: J9.A7 (D-), J9.B7 (D-), R48.1, R50.2, TP10.1
/Serial API TX: J9.A6 (D+), J9.B6 (D+), R49.1, TP10.2
/USB2_D+: J19.A6 (D+), J19.B6 (D+), R127.1, TP39.1 (1_1)
/USB2_D-: J19.A7 (D-), J19.B7 (D-), R128.1, TP40.1 (1_1)
/USB_D+: J11.A6 (D+), J11.B6 (D+), R70.1, TP20.1 (1_1)
/USB_D-: J11.A7 (D-), J11.B7 (D-), R71.1, TP21.1 (1_1)
/VREG2_AVDD: C82.1, R93.1, U20.61 (VREG_AVDD)
/VREG2_LX: L6.2, U20.63 (VREG_LX)
/VREG_AVDD: C45.1, R54.1, U14.61 (VREG_AVDD)
/VREG_LX: L4.2, U14.63 (VREG_LX)
/V_cont1: C8.2, D11.1 (K), D12.1 (K), L2.2
/Wht-Blue: J4.5, JP9.2, JP10.1, JP12.1
/Wht-Brown: J4.7, JP13.2, JP14.1, JP17.1
/Wht-Grn: J4.3, JP3.2, JP4.1, JP6.1
/Wht-Org: J4.1, JP27.2, JP28.1, JP29.1
/XIN: C39.1, U14.30 (XIN), Y1.1
/XIN_2: C70.1, U20.30 (XIN), Y2.1
/XOUT: R53.1, U14.31 (XOUT)
/XOUT_2: R92.1, U20.31 (XOUT)
/iso2+: C109.1, C112.1, C113.2, R148.2, R150.1, TP48.1, TR2.1 (TD-)
/iso2-: C110.1, C111.1, C113.1, R149.2, R150.2, TP48.2, TR2.3 (TD+)
/iso+: C96.1, C99.1, C103.2, R136.2, R142.1, TP42.1, TR1.1 (TD-)
/iso-: C97.1, C98.1, C103.1, R137.2, R142.2, TP42.2, TR1.3 (TD+)
Batt Negative: J17.10, J18.6, R121.2
Batt Positive: J17.1, J18.1, R120.2
C FC-Neg (GND): J6.37, J10.2, JP25.2 (B), JP26.2 (B)
C FC-Pos (GND): J6.36, J10.4, JP1.2, JP2.2
C Neg (GND): C34.2, D35.1 (K), D37.2 (A), D39.2 (A2), J6.42, J10.6, Q3.5 (D)
C Pos (GND): C15.2, D19.1 (K), D20.2 (A), D21.2 (A2), J6.41, J10.8, Q2.5 (D)
CAN2 Rx: D8.1 (K), J12.6, TP2.1, U10.2 (RXD), U14.2 (GPIO5)
CAN2 Tx: D10.1 (K), J12.4, TP2.2, U10.3 (TXD), U14.1 (GPIO4)
CAN Rx: R1.2, TP1.1, U5.2 (RXD), U14.20 (GPIO20)
CAN Tx: R3.2, TP1.2, U5.3 (TXD), U14.19 (GPIO19)
CTR-FC-NEG: R83.1, U11.4 (INB), U14.14 (GPIO15)
CTR-FC-Pos: R82.1, U1.4 (INB), U14.16 (GPIO16)
CTR-LNK-NEG: R81.1, U11.2 (INA), U14.17 (GPIO17)
CTR-LNK-POS: R77.1, U1.2 (INA), U14.18 (GPIO18)
CTR_EN: R141.2, R144.1, U1.1 (ENA), U1.8 (ENB), U11.1 (ENA), U11.8 (ENB)
Drive Unit Neg: H14.1 (1_1), K2.13, K4.14, K5.2, K7.13, K8.14, TH1.1, TH2.1, TH3.1
Emergency Stop: J12.18, J22.18, R13.2, U6.3, U14.9 (GPIO11), U20.9 (GPIO11)
Extra Input: J12.20, R14.2, U7.3, U14.11 (GPIO12)
Extra Output 1: R8.1, U14.12 (GPIO13)
Extra Output 2: R9.1, U14.13 (GPIO14)
FC Negative: J17.7, J18.4, R123.2
FC Positive: J17.4, J18.3, R122.2
FC-CTR-NEG-AUX: J12.16, R52.2, U13.3, U14.8 (GPIO10)
FC-CTR-POS-AUX: J12.14, R51.2, U12.3, U14.7 (GPIO9)
GND: C1.2, C2.1, C3.1, C4.1, C5.1, C6.1, C7.1, C8.1, C9.1, C10.2, C11.2, C12.1, C13.1, C14.2, C15.1, C17.1, C18.1, C22.1, C23.1, C26.1, C27.2, C29.1, C30.1, C31.2, C32.1, C33.1, C34.1, C35.1, C36.1, C37.1, C38.2, C39.2, C40.2, C43.2, C44.2, C45.2, C46.2, C47.2, C48.1, C49.1, C50.2, C51.2, C52.2, C53.2, C56.2, C58.2, C59.2, C61.2, C63.2, C65.2, C66.1, C67.1, C68.2, C69.1, C70.2, C71.2, C72.2, C73.1, C74.1, C75.2, C82.2, C83.2, C84.2, C85.2, C86.2, C87.2, C88.2, C89.2, C90.2, C91.1, C92.2, C93.2, C100.2, C101.2, C102.2, C104.1, D3.1 (A1), D6.1 (A1), D13.1 (K), D17.1 (K), D18.1 (A1), D21.1 (A1), D22.1 (K), D23.2 (A), D26.1 (A1), D30.1 (A1), D31.2 (A2), D34.1 (K), D39.1 (A1), D40.1 (A1), D46.1 (K), D48.1 (K), D49.1 (K), GND1.1 (1_1), J1.1, J1.2, J2.1 (Pin_1_1), J3.4, J5.3, J5.6, J5.15, J5.18, J5.SH, J6.3, J6.4, J6.30, J7.3, J7.4, J8.2, J9.A1 (GND), J9.A12 (GND), J9.B1 (GND), J9.B12 (GND), J9.SH (SHIELD), J11.A1 (GND), J11.A12 (GND), J11.B1 (GND), J11.B12 (GND), J11.SH (SHIELD), J12.11, J12.13, J12.15, J12.17, J12.19, J16.2, J19.A1 (GND), J19.A12 (GND), J19.B1 (GND), J19.B12 (GND), J19.SH (SHIELD), J22.11, J22.13, J22.15, J22.17, J22.19, Q1.1 (S), Q1.2 (S), Q1.3 (S), Q2.1 (S), Q2.2 (S), Q2.3 (S), Q3.1 (S), Q3.2 (S), Q3.3 (S), Q4.1 (S), Q4.2 (S), Q4.3 (S), R5.1, R10.1, R13.1, R14.1, R19.2, R21.2, R25.2, R27.2, R34.1, R36.1, R42.2, R51.1, R52.1, R74.1, R76.2, R77.2, R79.1, R80.1, R81.2, R82.2, R83.2, R88.2, R138.1, R139.1, R144.2, R146.1, SW1.1, SW2.1, SW3.1, SW4.1, TP3.1 (1_1), TP4.1, TP9.1, TP11.1 (1_1), TP16.1 (1_1), TP19.1 (1_1), TP23.1, TP24.1, TP38.1 (1_1), TP43.1, TP44.1, U1.3 (GND), U3.6 (GND), U3.9 (PowerPAD), U4.2 (-Vin), U5.4 (GND1), U8.2, U9.2, U10.4 (GND1), U10.5 (GND2), U11.3 (GND), U14.62 (VREG_PGND), U14.81 (GND), U15.2 (-Vin), U16.4 (GND1), U18.1 (ADDR), U18.3 (GND), U19.3 (GND), U20.62 (VREG_PGND), U20.81 (GND), U21.2 (~RE), U21.5 (GND), U22.8 (GND), U22.12 (~G), U25.1 (GND), Y1.2, Y1.4, Y2.2, Y2.4
GND2: A1.3 (GND), A1.8 (GND), A1.13 (GND), A1.18 (GND), A1.23 (GND), A1.28 (GND), A1.38 (GND), C105.2, C106.1, C114.1, U23.2 (~RE), U23.5 (GND), U24.8 (GND), U24.12 (~G)
GND CAN: C21.1, C24.1, C25.2, C28.1, D28.1 (A1), D29.2 (A2), D33.1 (K), J4.19, J4.SH, JP6.2, JP11.2, JP12.2, JP17.2, JP18.2, JP23.2, JP24.2, JP29.2, JP37.2, R30.2, TP5.1 (1_1), U4.5 (-Vout), U5.5 (GND2)
GND Shunt NTC -: C54.1, C55.1, C60.1, C64.1, C116.1, D45.1 (K), J14.1, J14.3, J15.2, R73.2, TP17.1 (1_1), U15.5 (-Vout), U16.5 (GND2), U17.1 (A1), U17.2 (A0), U17.7 (GND), U26.1 (GND); also elsewhere on the board
HMI Serial RX: R48.2, R130.1, U14.48 (GPIO39)
HMI Serial TX: R45.2, R49.2, R129.1, U14.47 (GPIO38)
I2C SCL Shunt: R57.2, TP15.2, U14.21 (GPIO21), U16.3 (SCL1)
I2C SCL Vsense: R90.2, TP25.2, U14.23 (GPIO23), U18.10 (SCL), U19.10 (SCL)
I2C SDA Shunt: R66.2, TP15.1, U14.25 (GPIO24), U16.2 (SDA1)
I2C SDA Vsense: R89.2, TP25.1, U14.22 (GPIO22), U18.9 (SDA), U19.9 (SDA)
IsoSPI2 RX H: A1.11 (GPIO8), TP46.1, U24.5 (2Y)
IsoSPI2 RX L: A1.12 (GPIO9), TP46.2, U24.3 (1Y)
IsoSPI2 TX Data: A1.10 (GPIO7), TP45.2, U23.4 (DI)
IsoSPI2 TX En: A1.9 (GPIO6), TP45.1, U23.3 (DE)
IsoSPI2+: J23.1, J24.1, TR2.4 (TX+)
IsoSPI2-: J23.2, J24.2, TR2.6 (TX-)
IsoSPI RX Debug: TP24.2, U14.39 (GPIO31)
IsoSPI RX Debug 2: TP43.2, U20.39 (GPIO31)
IsoSPI RX H: TP35.1, U14.36 (GPIO28), U20.36 (GPIO28), U22.5 (2Y)
IsoSPI RX L: TP35.2, U14.37 (GPIO29), U20.37 (GPIO29), U22.3 (1Y)
IsoSPI TX Data: TP34.2, U14.28 (GPIO27), U21.4 (DI)
IsoSPI TX En: TP34.1, U14.27 (GPIO26), U21.3 (DE)
IsoSPI+: J20.1, J21.1, TR1.4 (TX+)
IsoSPI-: J20.2, J21.2, TR1.6 (TX-)
Link Negative: J17.22, J18.5, R124.2
Link Positive: J17.13, J18.2, R125.2
MAIN-SUP TX/RX: R131.1, TP36.1, U14.79 (GPIO2)
MAX RX: J12.8, R133.2, U14.3 (GPIO6), U22.13 (4Y)
MAX RX2: A1.7 (GPIO5), U24.13 (4Y)
unnamed: BT1.1 (+), BT5.1 (+), K1.14, K6.14, R91.1
unnamed: BT1.2 (-), BT2.1 (+)
unnamed: BT2.2 (-), R86.2
unnamed: BT3.1 (+), F1.1
unnamed: BT3.2 (-), BT4.1 (+)
unnamed: BT4.2 (-), BT8.2 (-), K2.14, K7.14
unnamed: BT5.2 (-), BT6.1 (+)
unnamed: BT6.2 (-), R147.1
unnamed: BT7.1 (+), F3.1
unnamed: BT7.2 (-), BT8.1 (+)
unnamed: C19.1, J4.20, J4.21, JP37.1, U6.2
unnamed: C19.2, R22.1, U6.1
unnamed: C20.1, J4.14, J4.23, U7.2
unnamed: C20.2, R23.1, U7.1
unnamed: C40.1, R53.2, Y1.3
unnamed: C41.1, R46.2, U12.2
unnamed: C42.1, R47.2, U13.2
unnamed: C71.1, R92.2, Y2.3
unnamed: C94.1, TP37.2
unnamed: C95.1, TP37.1
unnamed: C107.1, TP47.2
unnamed: C108.1, TP47.1
unnamed: Cell1.1 (+), R58.1, R59.1
unnamed: Cell1.2 (-), Cell2.1 (+), R60.1, R61.1
unnamed: Cell2.2 (-), Cell3.1 (+), R62.1, R63.1
unnamed: Cell3.2 (-), R64.1, R65.1
unnamed: D1.1 (A1), D2.2 (A2)
unnamed: D2.1 (A1), D3.2 (A2)
unnamed: D4.1 (A1), D5.2 (A2)
unnamed: D5.1 (A1), D6.2 (A2)
unnamed: D7.1 (K), R1.1
unnamed: D8.2 (A), R2.2
unnamed: D9.1 (K), R3.1
unnamed: D10.2 (A), R4.2
unnamed: D13.2 (A), R151.1
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

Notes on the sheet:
all JLC basic components
3.3V 1A LDO Supply
GPIO3 - GPIO12 on NC header
external NC switch for estop, or jumper to disable.
Not tested as of now
I2C ADDR: 0x49
Aux Input 3-5V limited by resistor dissipation for higher input voltage use external series resistor
FC Negative Contactor
Would be cool if it alternates with main
PTC 440V 56Ω
BMB side xfmr center tap has no connection reference to ground to prevent ESD
Use 3v3 so no logic translation necessary.
TX must be on this pin
GND to battery chassis
unused inputs left floating - internal bias
3A max output - 3.3V draws from this rail
1.122V
1.52V
FC positive contactor not used (no 12V connection)
100k input impedance 0.14mA typical ADC usage
Gate driver has internal 200k pullup, 2x in parallel = 100k pullup must pull down to always start in off state.
L must be after H
DIY connector
BMB Connector
MCU Identification
In tesla packs the shunt is at the mid point of the pack and always live!
second ADS1115: 0-1 linkneg - outpos 0-3 linkneg - linkpos <- link voltage 1-3 outpos - linkpos <- voltage across FC pos contactor 2-3 batpos - linkpos <- voltage across battery pos contactor
Supervisor MCU
5V powers exteral ESP32 LCD also
pyro is always live
FC Positive Contactor
Cells to Positive Link Contactor
close to MCU
Aux contacts inside of the FC contactors used to check for welding with or without energizing
Extra GPIO
API TTL RS232 HMI Interface
Redundant connectors
FC negative controls pre-charge bypass
Galvanically Isolated Area
Data must be after En

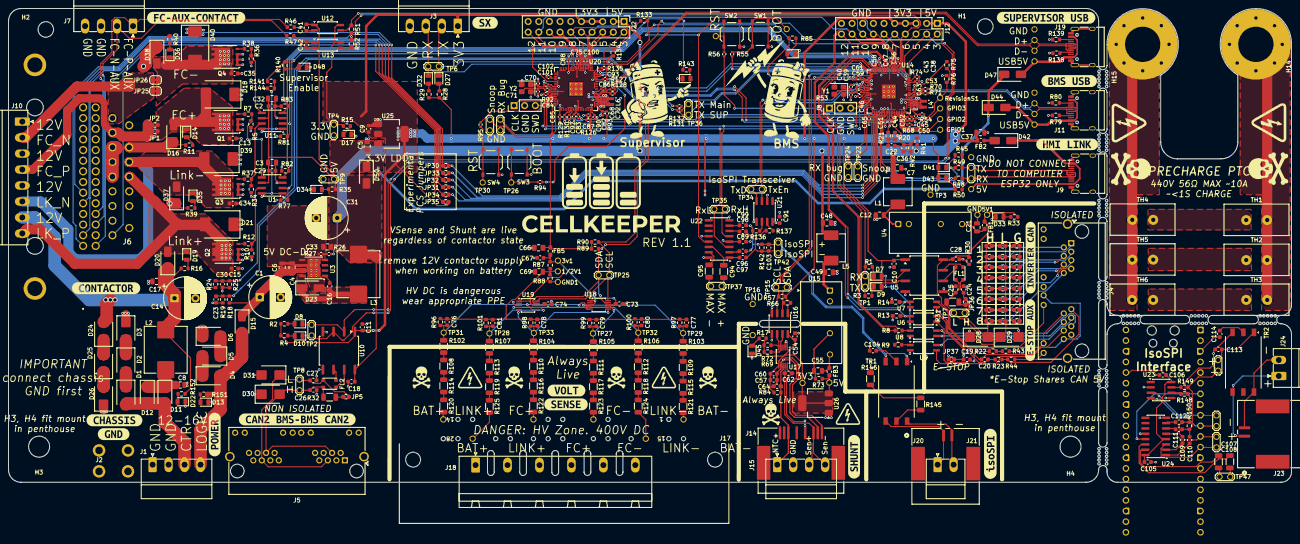
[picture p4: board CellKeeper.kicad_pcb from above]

Board: 4 copper layers, 306.0 x 113.0 mm, 506 parts (1 on the bottom side), 294 nets.

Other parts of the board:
C57: 1uF; Capacitor_SMD__C_0603_1608Metric
kibuzzard-6A455E05: G***; kibuzzard-6A455E05
kibuzzard-6A455E28: G***; kibuzzard-6A455E28
kibuzzard-6A455E35: G***; kibuzzard-6A455E35
kibuzzard-6A455ED1: G***; kibuzzard-6A455ED1
kibuzzard-6A455F32: G***; kibuzzard-6A455F32
kibuzzard-6A455FAF: G***; kibuzzard-6A455FAF
kibuzzard-6A455FB8: G***; kibuzzard-6A455FB8
kibuzzard-6A4560A1: G***; kibuzzard-6A4560A1
kibuzzard-6A4560DE: G***; kibuzzard-6A4560DE
kibuzzard-6A4561AC: G***; kibuzzard-6A4561AC
kibuzzard-6A6094FF: G***; kibuzzard-6A6094FF
kibuzzard-6A45612B: G***; kibuzzard-6A45612B
kibuzzard-6A45614A: G***; kibuzzard-6A45614A
kibuzzard-6A456096: G***; kibuzzard-6A456096
kibuzzard-6A456143: G***; kibuzzard-6A456143
kibuzzard-6A456164: G***; kibuzzard-6A456164

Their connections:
GND Shunt NTC -: C57.1; also elsewhere on the board
Shunt_3V3: C57.2; also elsewhere on the board

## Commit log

2026-07-22 start on rev1.1
    [CellKeeper.kicad_pcb, CellKeeper.kicad_sch]
2026-07-28 added 3v3 regulator to the INA228 isolated zone
    [CellKeeper.kicad_pcb, CellKeeper.kicad_sch]
